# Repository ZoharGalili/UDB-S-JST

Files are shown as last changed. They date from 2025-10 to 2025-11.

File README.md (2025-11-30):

# Modified Unified Daughterboard S 

## Changes 

- switched to the reliable JST connector.
- replaced esd chip to the SRV05-4.
- changed the fotprint to 0805.
- switched to a 2 layer pcb.

## Why Change?

i made a custom keyboard design a while ago with the UDS-S and i hand soldered all the components myself because im broke. 
there were a few problems i encountered with the doughterboard:
- the board was extremely difficult to solder. expecially the tiny esd chip.
- the ezmate molex connector is trash. after soldering up the board the connector kept snapping off the board.
i dont know why the connector kept snapping off but the fact that it pulls up to dissconnect only encourages its snapping off.
- i switched to 2 layer just because i didnt use more than the 2 layers when routing.

honestly i dont know if ill make this design but well see...

## Previews
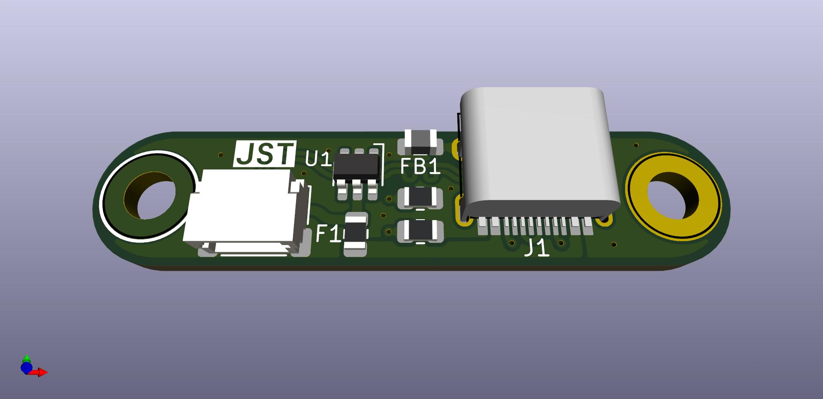
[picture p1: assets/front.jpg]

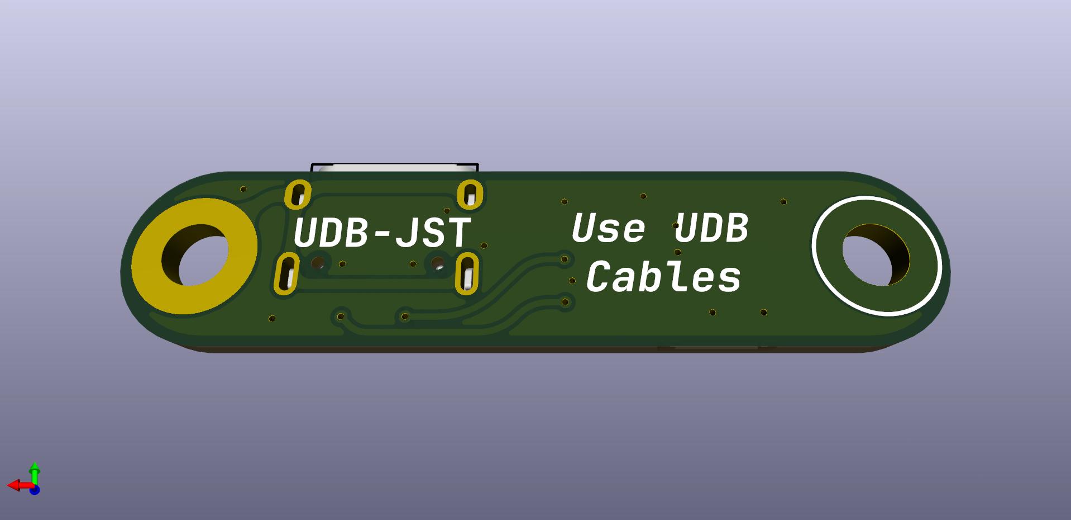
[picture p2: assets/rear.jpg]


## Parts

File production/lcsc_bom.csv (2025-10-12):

Designator | Footprint | Quantity | Value | LCSC Part #
F1 | 805 | 1 | SMD0805-050-16V | C2833485
FB1 | 805 | 1 | ~ | C21286
J1 | HRO-TYPE-C-31-M-12-Assembly | 1 | TYPE-C-31-M-12 | C165948
J2 | JST_SH_SM04B-SRSS-TB_1x04-1MP_P1.00mm_Horizontal | 1 | WAFER-SH1.0-4PWB | C3029343
R1, R2 | 805 | 2 | 5.1k | C27834
U1 | SOT-23-6-routable | 1 | SRV05-4 | C2836319

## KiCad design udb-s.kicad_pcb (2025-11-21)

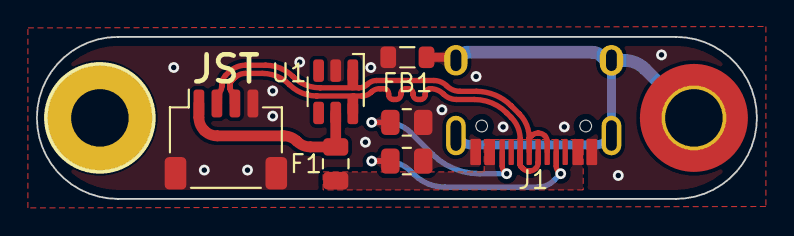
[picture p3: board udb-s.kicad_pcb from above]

Board: 2 copper layers, 40.0 x 9.0 mm, 9 parts (0 on the bottom side), 8 nets.

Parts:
F1: SMD0805-050-16V; Fuse_0805_2012Metric
FB1: L_0805_2012Metric
H1: MountingHole; MountingHole_3.2mm_M3_DIN965_Pad_TopBottom
H2: MountingHole; MountingHole_3.2mm_M3_DIN965_Pad_TopOnly
J1: TYPE-C-31-M-12; HRO-TYPE-C-31-M-12-Assembly
JST: WAFER-SH1.0-4PWB; JST_SH_SM04B-SRSS-TB_1x04-1MP_P1.00mm_Horizontal
R1, R2: 5.1k; R_0805_2012Metric
U1: SRV05-4; SOT-23-6-routable

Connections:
5V: F1.2, JST.1, U1.5 (VP)
D+: J1.A6 (D+), J1.B6 (D+), JST.3, U1.6 (IO4)
D-: J1.A7 (D-), J1.B7 (D-), JST.2, U1.1 (IO1)
GND: FB1.2, J1.A1 (GND), J1.B1 (GND), JST.4, JST.MP (MountPin), R1.1, R2.2, U1.2 (VN)
GNDPWR: FB1.1, H1.1, J1.S1 (SHIELD)
unnamed: J1.A5 (CC1), R1.2
unnamed: J1.B5 (CC2), R2.1
VBUS: F1.1, J1.A4 (VBUS), J1.B4 (VBUS)

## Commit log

2025-06-09 the pcb
    changed everything i wanted
    [udb-s.kicad_pcb, udb-s.kicad_sch]
2025-06-09 generated production files
    [bom.csv, designators.csv, positions.csv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]
2025-06-14 BOM done
    [bom.csv]
2025-08-13 fixed usb traces + teardrops
    the usb traces were only connected to two of the pins on the usb connector
    [udb-s.kicad_pcb]
2025-08-14 made production files + BOM
    generated the production files and filled out the BOM using lcsc components
    [bom.csv, positions.csv, udb-s.kicad_pcb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]
2025-08-15 cheaper jst connector
    changed to a cheaper jst connector (XUNPU WAFER-SH1.0-4PWB)
    [bom.csv]
2025-10-04 final tweeks
    the USB pair impedance is now closer to 90 and has less interruptions in its reference ground plane
    [bom.csv, positions.csv, udb-s.kicad_pcb]
2025-10-05 swapped to SRV05-4
    swapped the esd chip to the SRV05-4 and removed the singular diode because its built into the esd chip
    [bom.csv, designators.csv, positions.csv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]
2025-11-21 usb length matching
    made the usb line length matching as well as some other minor stuff
    [designators.csv, lcsc_bom.csv, positions.csv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]
2025-11-30 updated renders
    updated the renders of the board to those that are the newest version
